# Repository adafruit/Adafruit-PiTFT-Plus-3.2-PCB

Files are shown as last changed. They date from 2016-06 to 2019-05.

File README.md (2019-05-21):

## Adafruit PiTFT Plus 320x240 3.2" TFT + Resistive Touchscreen PCB
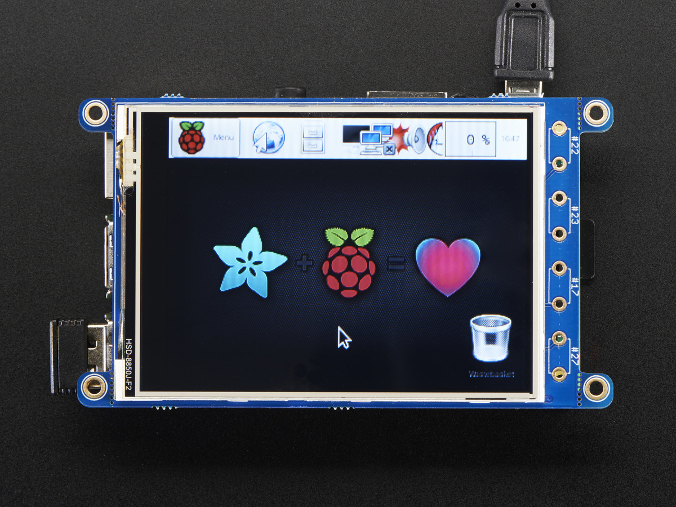
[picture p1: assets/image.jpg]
<a href="http://www.adafruit.com/products/2616"><br/>
Click here to purchase one from the Adafruit shop</a>

Is this not the cutest little display for the Raspberry Pi? It features a 3.2" display with 320x240 16-bit color pixels and a resistive touch overlay. The plate uses the high speed SPI interface on the Pi and can use the mini display as a console, X window port, displaying images or video etc. Best of all it plugs right in on top!

This design fits perfectly onto the Pi Zero, Pi 3, Pi 2 or Model A+, B+! (Any Pi with a 2x20 connector) Not for use with an old Pi 1 with 2x13 connector. This display is functionally the same as our classic PiTFT 2.8" and PiTFT Plus 2.8" - same pins used, same resolution, same drivers, but is just a bit bigger. It also has a 26- pins GPIO pins brought out so you can connect a 26-pin Raspberry Pi GPIO cable underneath. It's the same outline as a Pi 3 / 2 / B+ so it fits well on top of a Pi in our Raspberry Pi Enclosure base.

PCB files for the Adafruit PiTFT Plus 3.2" Display. The format is EagleCAD schematic and board layout
- https://www.adafruit.com/product/2616

### License

Adafruit invests time and resources providing this open source design, please support Adafruit and open-source hardware by purchasing products from [Adafruit](https://www.adafruit.com)!

All text above must be included in any redistribution

Designed by Limor Fried/Ladyada for Adafruit Industries.
Creative Commons Attribution/Share-Alike, all text above must be included in any redistribution. 
See license.txt for additional information.

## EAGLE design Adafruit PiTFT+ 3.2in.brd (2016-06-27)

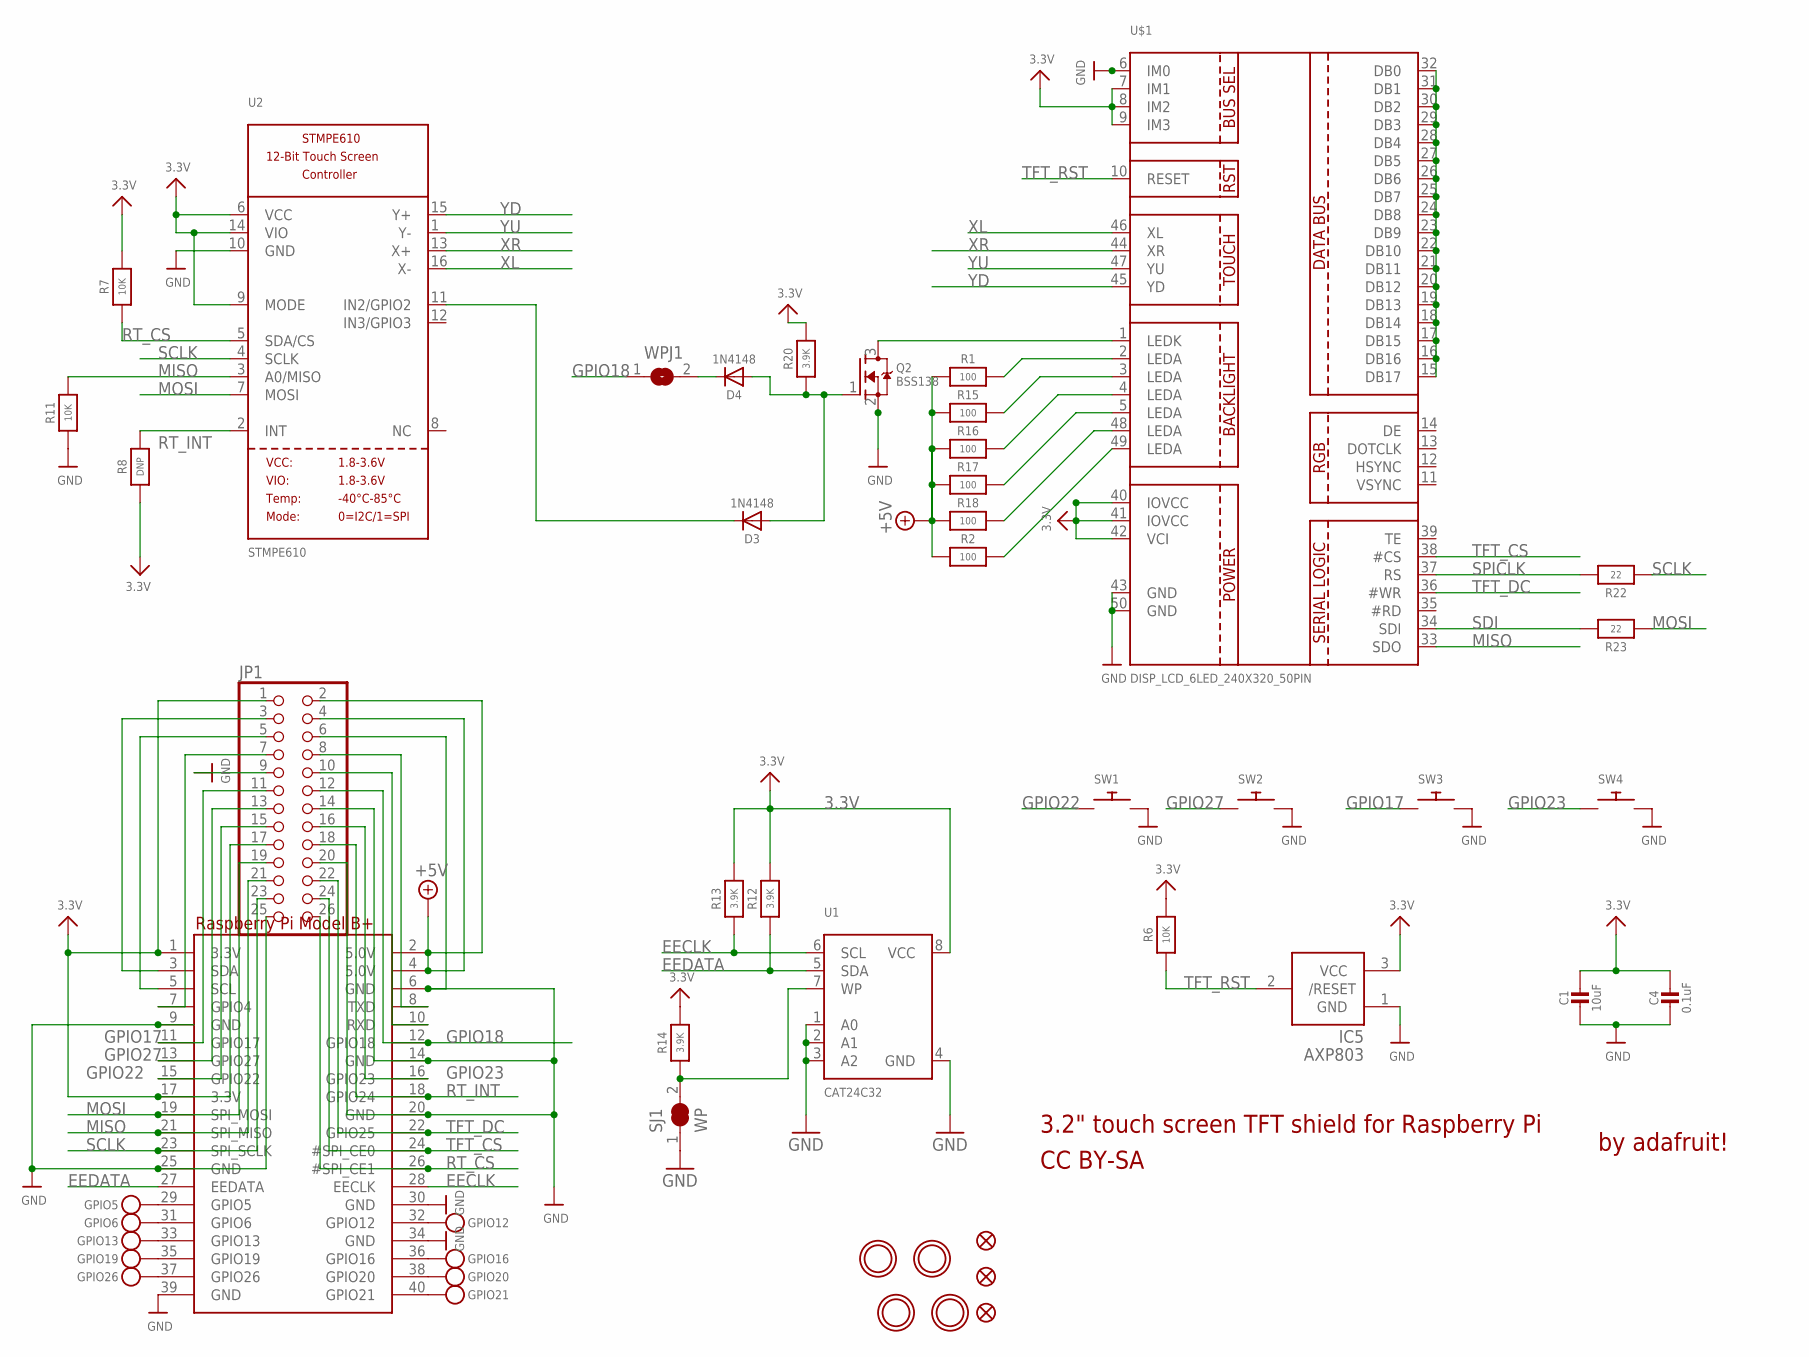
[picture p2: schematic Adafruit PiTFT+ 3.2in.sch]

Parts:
C1: 10uF; 0805-NO
C4: 0.1uF; 0805-NO
D3, D4: 1N4148; SOD-323
GPIO5, GPIO6, GPIO12, GPIO13, GPIO16, GPIO19, GPIO20, GPIO21, GPIO26: TESTPOINT1.5X2.0MM_NOCREAM; PAD-1.5X2.0
IC5: AXP803; SOT23
JP1: HEADER-2X13-SMT; 2X13_SMT_MALE
Q2: BSS138; SOT23-WIDE
R1, R2, R15, R16, R17, R18: 100; 0805-NO
R6, R7, R11: 10K; 0805-NO
R8: DNP; 0805-NO
R12, R13, R14, R20: 3.9K; 0805-NO
R22: 22; 0805-NO
R23: 22; _0805MP
RPI1: RASPBERRYPI_BPLUS_SMT; RASPBERRYPI_BPLUS_SHIELD_SMT
SJ1: WP; SOLDERJUMPER_CLOSEDWIRE
SW1, SW2, SW3, SW4: SWITCH_PUSHBUTTONEVQ-PE; TACT_PANA-EVQ
U1: CAT24C32; SOIC8_150MIL
U2: STMPE610; QFN16_3MM
U$1: DISP_LCD_6LED_240X320_50PIN; TFT_3.2IN_240X320_50PIN
U$10, U$11, U$18: FIDUCIAL""; FIDUCIAL_1MM
U$15, U$16, U$17, U$20: MOUNTINGHOLE2.5_THICK; MOUNTINGHOLE_2.5_PLATED_THICK
WPJ1: SOLDERJUMPERCLOSED; SOLDERJUMPER_CLOSEDWIRE

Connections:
3.3V: C1.1, C4.1, IC5.3 (VCC), JP1.1, JP1.17, R6.2, R7.2, R8.1, R12.2, R13.2, R14.2, R20.2, RPI1.1 (3.3V), RPI1.17 (3.3V), U1.8 (VCC), U2.6 (VCC), U2.9 (MODE), U2.14 (VIO), U$1.7 (IM1), U$1.8 (IM2), U$1.9 (IM3), U$1.40 (IOVCC), U$1.41 (IOVCC), U$1.42 (VCI)
+5V: JP1.2, JP1.4, R1.1, R2.1, R15.1, R16.1, R17.1, R18.1, RPI1.2 (5.0V), RPI1.4 (5.0V)
EECLK: R13.1, RPI1.28 (EECLK), U1.6 (SCL)
EEDATA: R12.1, RPI1.27 (EEDATA), U1.5 (SDA)
GND: C1.2, C4.2, IC5.1 (GND), JP1.6, JP1.9, JP1.14, JP1.20, JP1.25, Q2.2 (S), R11.1, RPI1.6 (GND), RPI1.9 (GND), RPI1.14 (GND), RPI1.20 (GND), RPI1.25 (GND), RPI1.30 (GND), RPI1.34 (GND), RPI1.39 (GND), SJ1.1, SW1.P$2, SW2.P$2, SW3.P$2, SW4.P$2, U1.1 (A0), U1.2 (A1), U1.3 (A2), U1.4 (GND), U2.10 (GND), U$1.6 (IM0), U$1.43 (GND), U$1.50 (GND)
GPIO6: GPIO6.P$1, RPI1.31 (GPIO6)
GPIO16: GPIO16.P$1, RPI1.36 (GPIO16)
GPIO17: JP1.11, RPI1.11 (GPIO17), SW3.P$1
GPIO18: JP1.12, RPI1.12 (GPIO18), WPJ1.1
GPIO22: JP1.15, RPI1.15 (GPIO22), SW1.P$1
GPIO23: JP1.16, RPI1.16 (GPIO23), SW4.P$1
GPIO27: JP1.13, RPI1.13 (GPIO27), SW2.P$1
MISO: JP1.21, R11.2, RPI1.21 (SPI_MISO), U2.3 (A0/MISO), U$1.33 (SDO)
MOSI: JP1.19, R23.1, RPI1.19 (SPI_MOSI), U2.7 (MOSI)
unnamed: R2.2, U$1.49 (LEDA)
unnamed: R1.2, U$1.2 (LEDA)
unnamed: D3.C, U2.11 (IN2/GPIO2)
unnamed: GPIO5.P$1, RPI1.29 (GPIO5)
unnamed: JP1.3, RPI1.3 (SDA)
unnamed: JP1.5, RPI1.5 (SCL)
unnamed: JP1.7, RPI1.7 (GPIO4)
unnamed: GPIO13.P$1, RPI1.33 (GPIO13)
unnamed: GPIO19.P$1, RPI1.35 (GPIO19)
unnamed: GPIO26.P$1, RPI1.37 (GPIO26)
unnamed: GPIO12.P$1, RPI1.32 (GPIO12)
unnamed: GPIO20.P$1, RPI1.38 (GPIO20)
unnamed: R14.1, SJ1.2, U1.7 (WP)
unnamed: JP1.10, RPI1.10 (RXD)
unnamed: JP1.8, RPI1.8 (TXD)
unnamed: GPIO21.P$1, RPI1.40 (GPIO21)
unnamed: D3.A, D4.A, Q2.1 (G), R20.1
unnamed: U$1.15 (DB17), U$1.16 (DB16), U$1.17 (DB15), U$1.18 (DB14), U$1.19 (DB13), U$1.20 (DB12), U$1.21 (DB11), U$1.22 (DB10), U$1.23 (DB9), U$1.24 (DB8), U$1.25 (DB7), U$1.26 (DB6), U$1.27 (DB5), U$1.28 (DB4), U$1.29 (DB3), U$1.30 (DB2), U$1.31 (DB1), U$1.32 (DB0)
unnamed: Q2.3 (D), U$1.1 (LEDK)
unnamed: R15.2, U$1.3 (LEDA)
unnamed: R16.2, U$1.4 (LEDA)
unnamed: R17.2, U$1.5 (LEDA)
unnamed: R18.2, U$1.48 (LEDA)
unnamed: D4.C, WPJ1.2
RT_CS: JP1.26, R7.1, RPI1.26 (#SPI_CE1), U2.5 (SDA/CS)
RT_INT: JP1.18, R8.2, RPI1.18 (GPIO24), U2.2 (INT)
SCLK: JP1.23, R22.1, RPI1.23 (SPI_SCLK), U2.4 (SCLK)
SDI: R23.2, U$1.34 (SDI)
SPICLK: R22.2, U$1.37 (RS)
TFT_CS: JP1.24, RPI1.24 (#SPI_CE0), U$1.38 (#CS)
TFT_DC: JP1.22, RPI1.22 (GPIO25), U$1.36 (#WR)
TFT_RST: IC5.2 (/RESET), R6.1, U$1.10 (RESET)
XL: U2.16 (X-), U$1.46 (XL)
XR: U2.13 (X+), U$1.44 (XR)
YD: U2.15 (Y+), U$1.45 (YD)
YU: U2.1 (Y-), U$1.47 (YU)

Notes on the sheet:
3.2" touch screen TFT shield for Raspberry Pi
by adafruit!
CC BY-SA

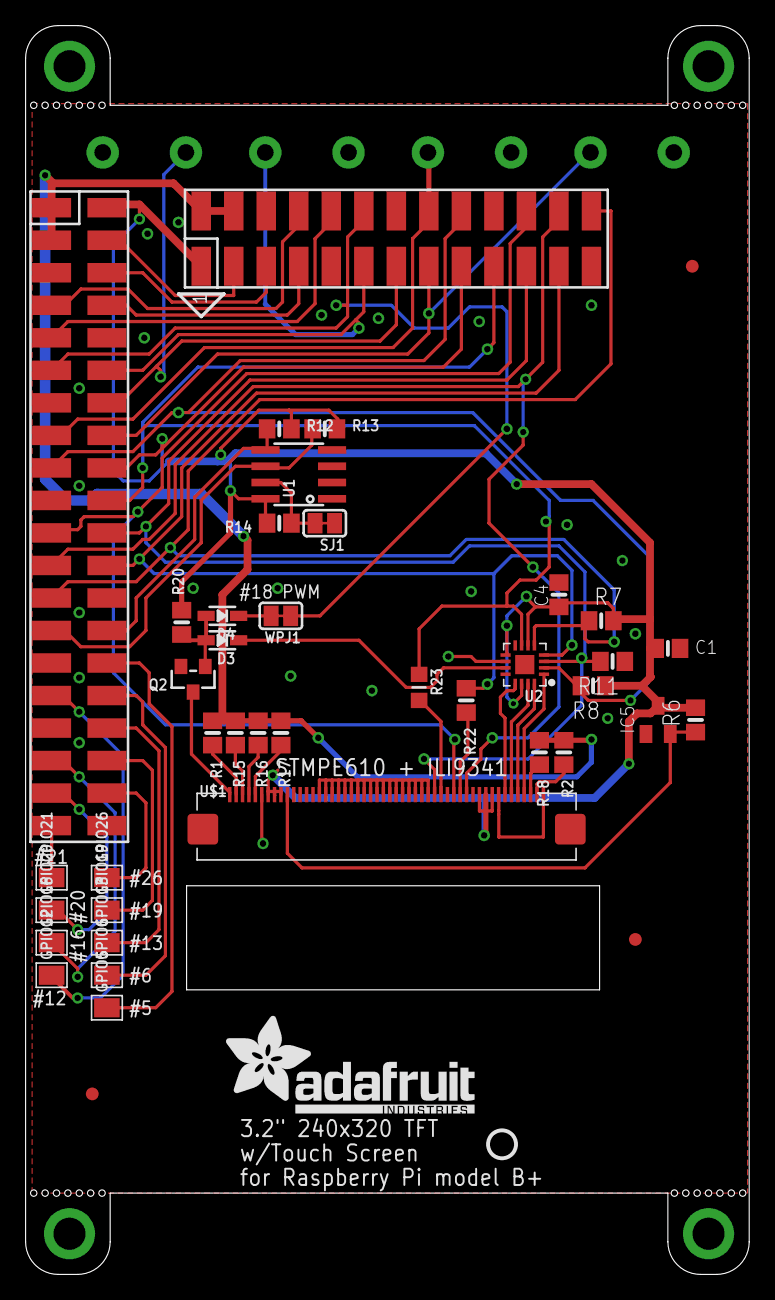
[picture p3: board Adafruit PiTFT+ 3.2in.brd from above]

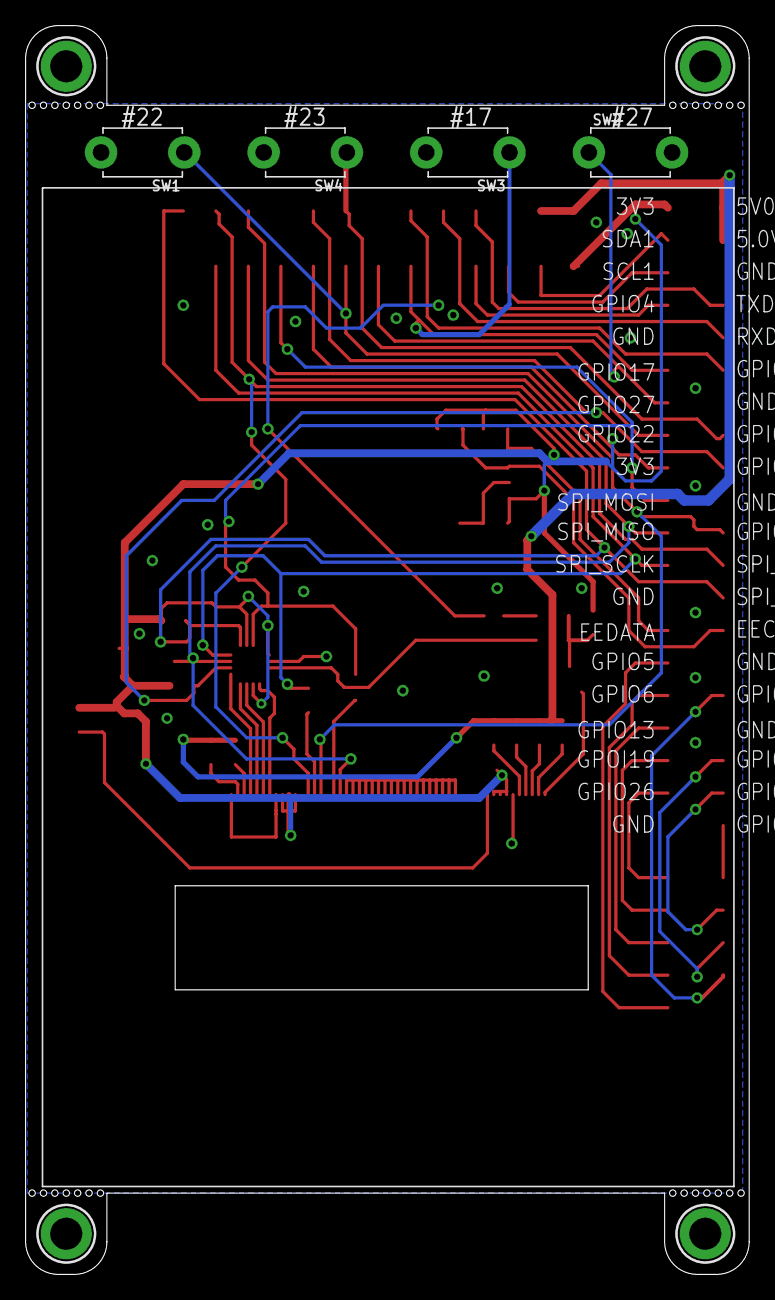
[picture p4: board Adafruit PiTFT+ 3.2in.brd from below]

Board: 2 copper layers, 56.5 x 97.5 mm, 51 parts (10 on the bottom side), 50 nets.

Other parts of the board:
U$19: PCBFEAT-REV-056
U$23: ADAFRUIT_TEXT_20MM
